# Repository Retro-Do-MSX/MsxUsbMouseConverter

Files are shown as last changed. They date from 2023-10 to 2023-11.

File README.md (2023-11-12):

# MsxUsbMouseConverter
MSX USBマウス変換器  
MSX USB Mouse converter  

## 概要
- PC用USBマウスをMSXのインテリジェントマウスとして使用するための変換器です
- 組み立てにはハンダ付けが必要です
- ケースは購入可能です、3Dプリンター用モデルも無料提供しています
- サポートはありません

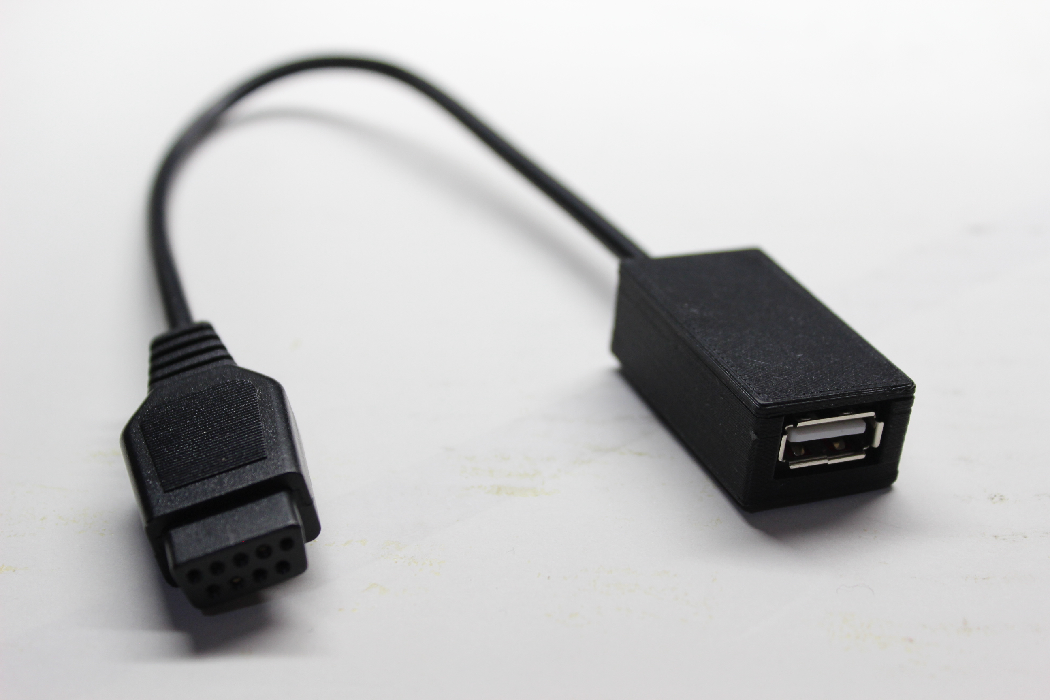
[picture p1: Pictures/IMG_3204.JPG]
converter1


## 動作
- 本機はMSX用マウスモードのみで動作します。モード切替はありません

- ホイール上下で感度(解像度)が5段階変化します

## 動作検証
- 以下のソフトで問題なく動作することを確認しました
  - 秘録 首斬り館 〜逐電屋藤兵衛〜（マウス）
  - スーパーグラフィックツール ダ・ビンチ（マウス）
  - NEOSグラフィックソフト CHEESE2（マウス）
  - FS-A1GT MSX-VIEW（マウス）

- 以下のマウスで動作を確認しています
  - iBuffalo BSMRW21 USB無線マウス
  - Logicool M705 USB無線マウス

- 電力消費の大きなLED付き有線マウスは動作しない可能性があります

## キット内容
- 変換基板 x1
- マイコン基板 (ソフトウェア書込み済) x1
- USB Type A メスコネクタ x1
- 抵抗 22Ω x2
- ピンヘッダ x2
- D-SUB 9ピンコントローラ用ケーブル x1
- ケース (オプション) 上下組 x1
  ※お届けする商品は画像のものと異なる場合があります

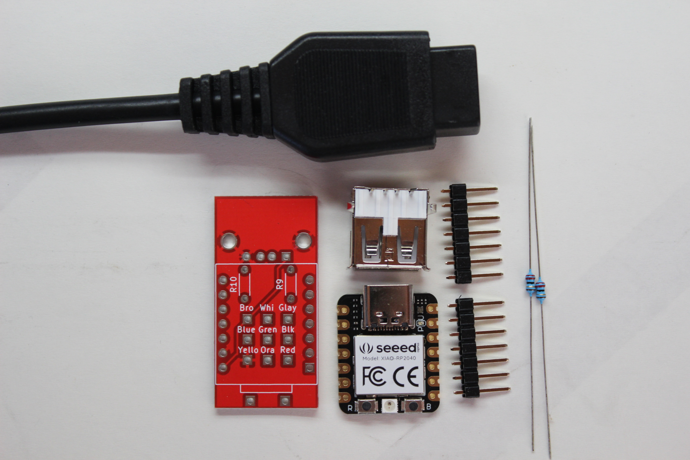
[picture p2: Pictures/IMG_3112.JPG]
parts
  
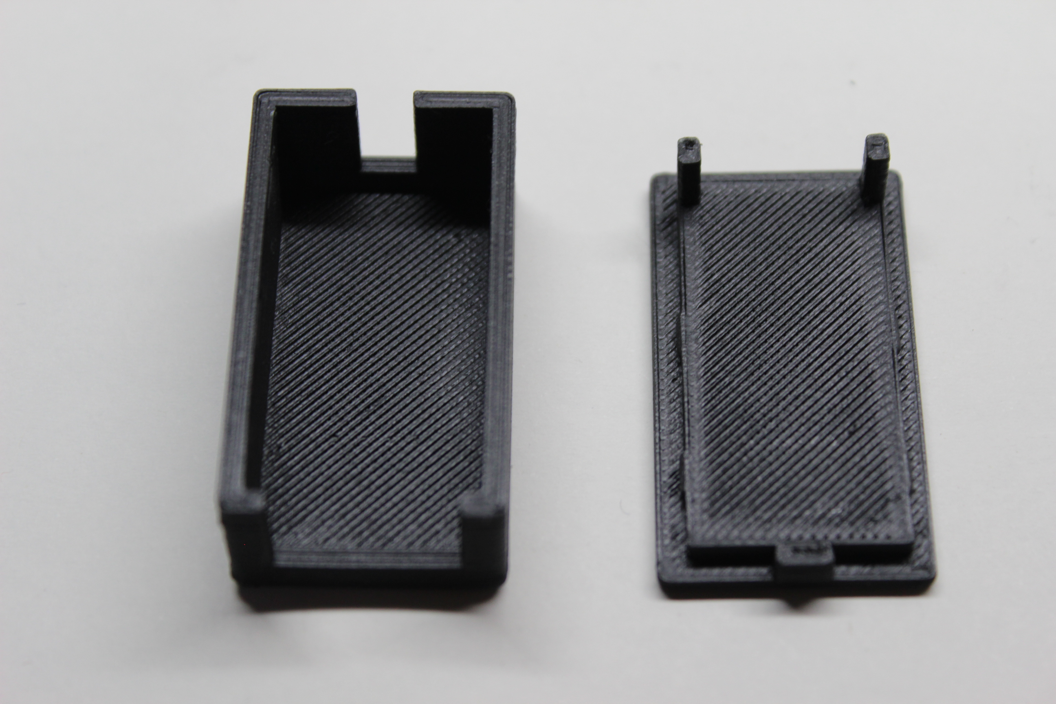
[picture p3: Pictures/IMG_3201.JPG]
case
   

## 注意事項
- マイコン基板のUSB Type Cコネクタは接続しないでください  
  PCと接続すると書き込み済みのファームウェアが消える可能性があります
- 万一プログラムが消えた場合の再書き込みは有償での対応となります

## 組立方法
- D-SUB 9ピンコントローラ用ケーブルの先端を剥き予備ハンダしておきます

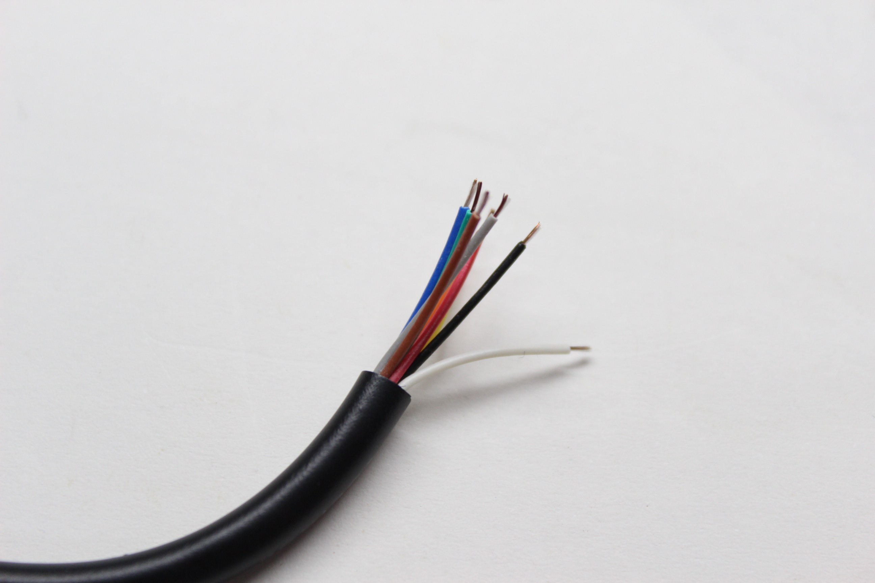
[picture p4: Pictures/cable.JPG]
cable
  

- 変換基板のシルクに書かれた色に合わせて9本のケーブルをハンダ付けします

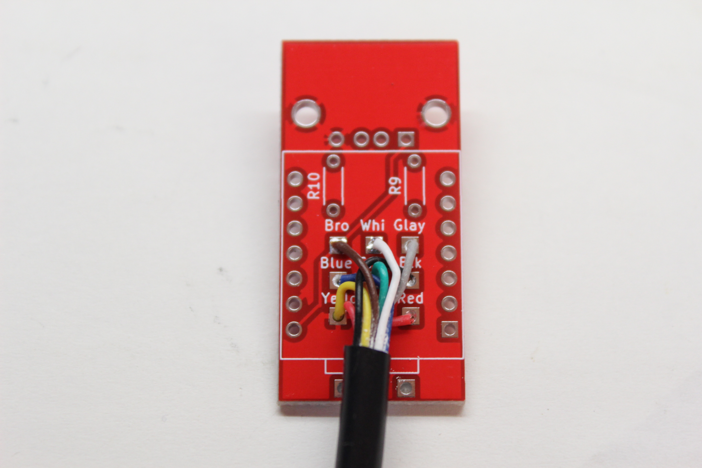
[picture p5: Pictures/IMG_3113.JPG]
1st step


- 部品の足などを使用してケーブルの抜け止めをハンダ付けします（キットには含まれません）
  - シルクの線を目安に黒い被膜がマイコン基板に干渉しないようにします

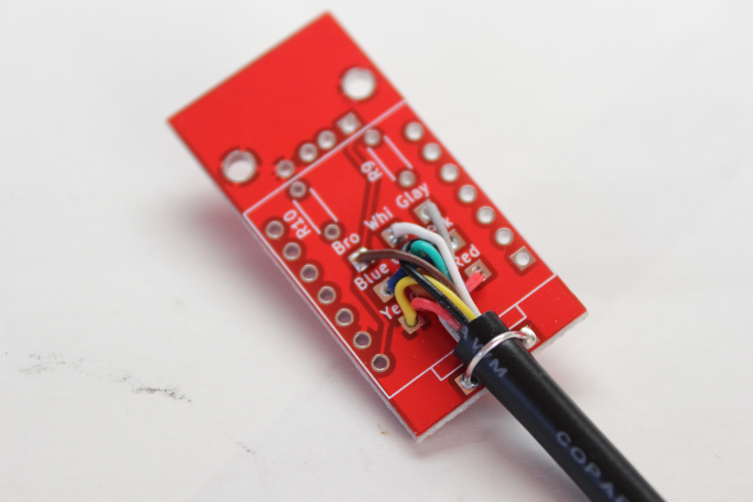
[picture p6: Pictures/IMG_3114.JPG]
2nd step


- 抵抗2本を取り付けます

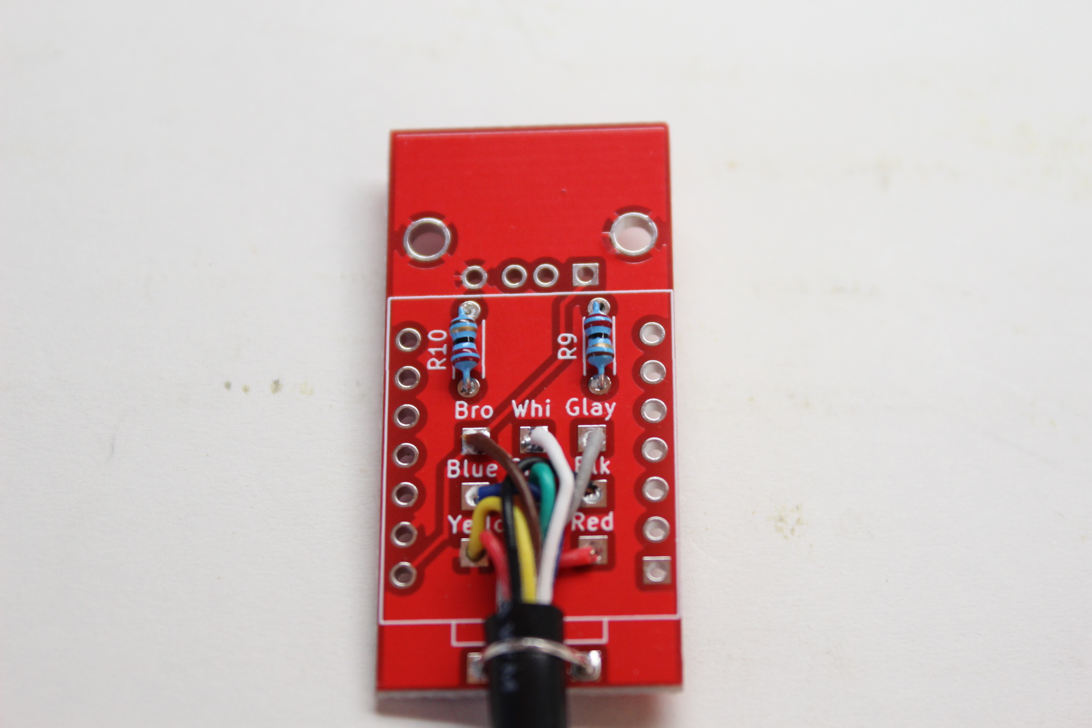
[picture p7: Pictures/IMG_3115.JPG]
3rd step


- USBコネクタとマイコン基板を取り付けます

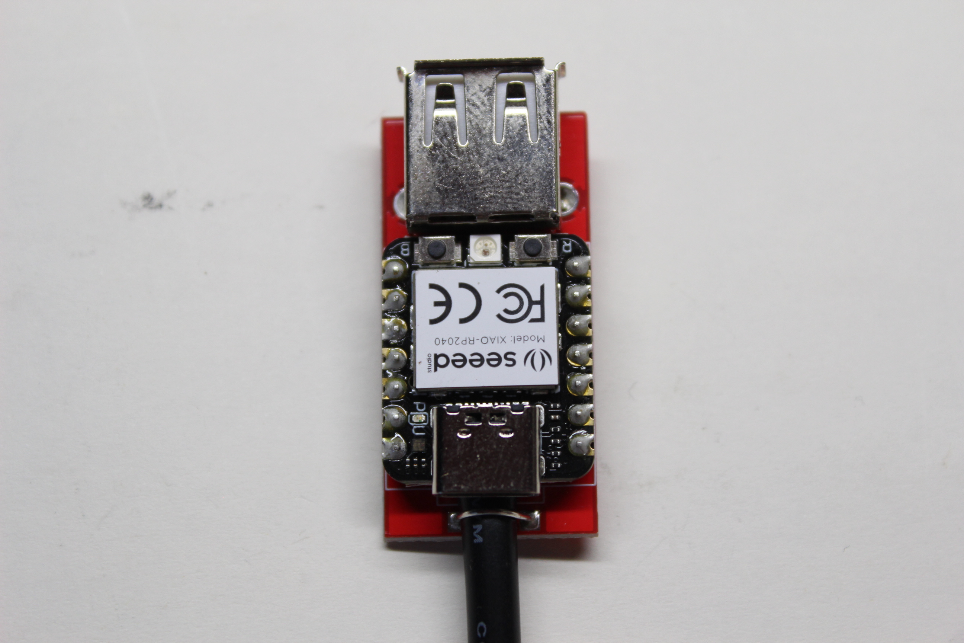
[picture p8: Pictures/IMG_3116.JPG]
4th step


- 裏面に飛び出したピンヘッダやコネクタの足はできるだけ短くカットします
  - ケースに入れない場合は絶縁テープなどを貼りショートしないようにします

- 2023年版は配線漏れがあったため下記のジャンパを追加してください
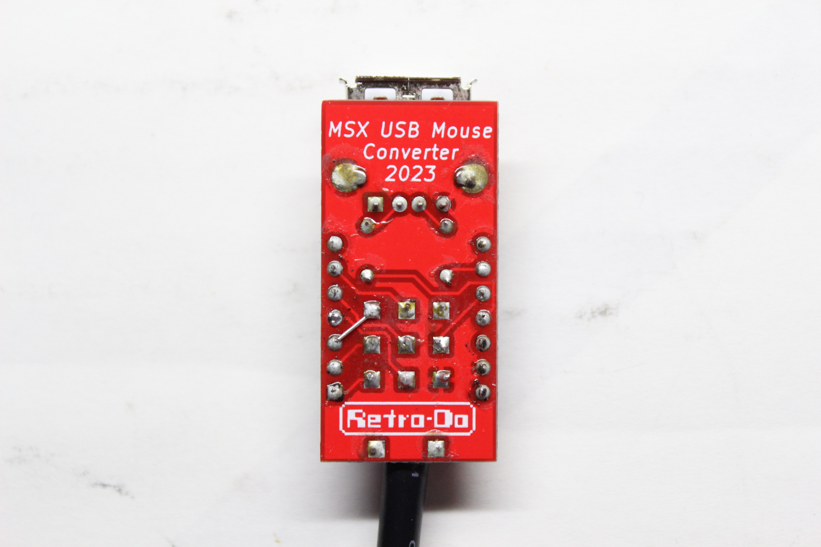
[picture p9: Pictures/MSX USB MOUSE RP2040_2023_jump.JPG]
2023ジャンパ
  

- ケースに入れます

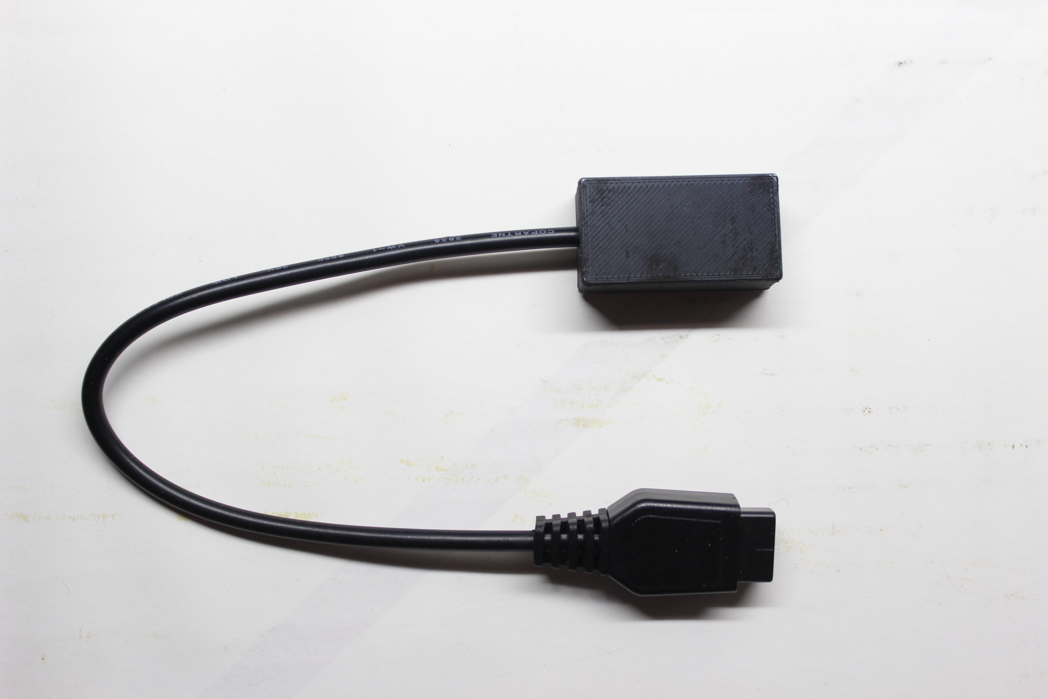
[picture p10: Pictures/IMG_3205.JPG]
converter2


## ケースのプリント用データ

https://github.com/Retro-Do-MSX/MsxUsbMouseConverter/blob/main/Models/Bottom%20MSX%20USB%20Mouse%20Converter%20case.stl
https://github.com/Retro-Do-MSX/MsxUsbMouseConverter/blob/main/Models/Upper%20MSX%20USB%20Mouse%20Converter%20case.stl

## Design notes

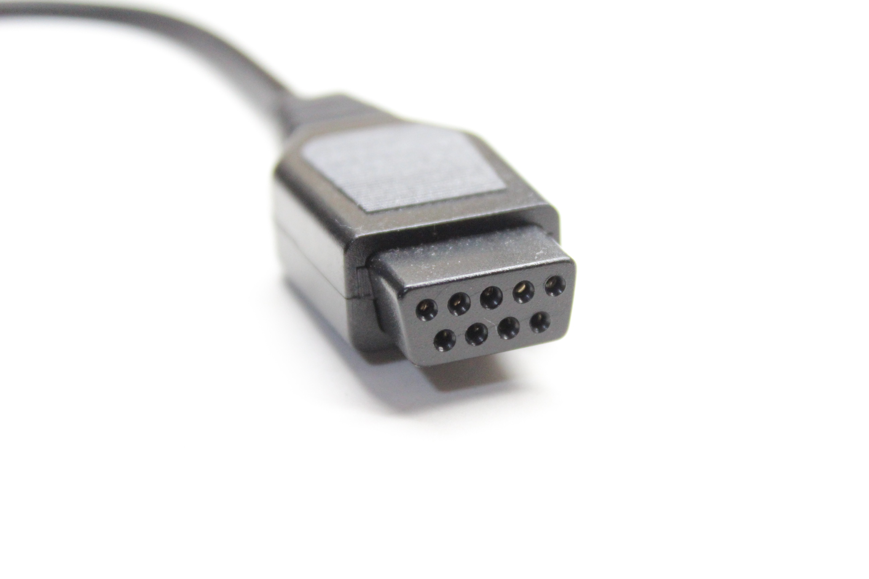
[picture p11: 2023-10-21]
Pictures/JOYcon.JPG

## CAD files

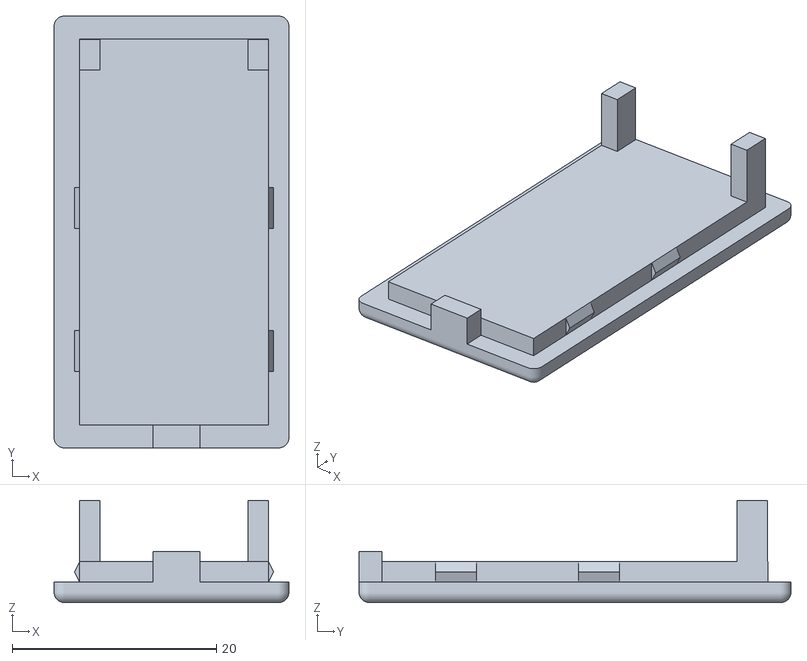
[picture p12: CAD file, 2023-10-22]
Models/Upper MSX USB Mouse Converter case.stl
23.0 x 42.3 x 10.0

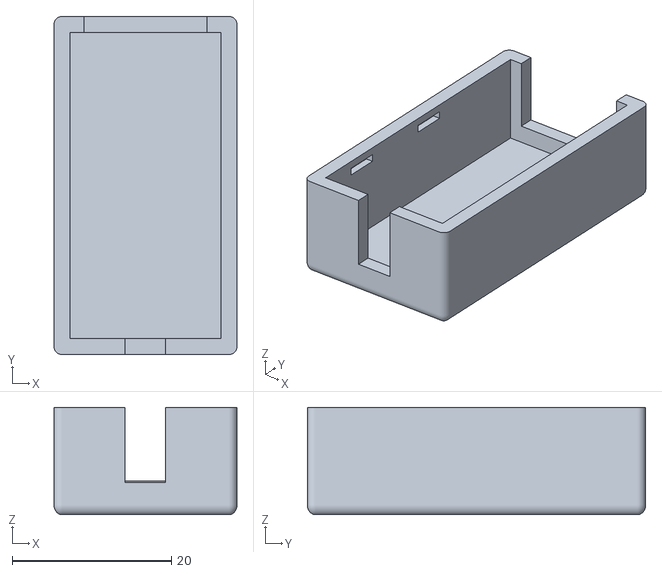
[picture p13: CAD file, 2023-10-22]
Models/Bottom MSX USB Mouse Converter case.stl
23.0 x 42.5 x 13.5

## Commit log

2023-10-21 初期コミット Retro-Do
2023-10-22 ケース写真を追加 Retro-Do
2023-10-22 ケースの3Dモデルを追加 Retro-Do
    [Bottom MSX USB Mouse Converter case.stl, Upper MSX USB Mouse Converter case.stl]
2023-10-22 写真を入れ替え
    Retro-Do
2023-10-22 写真の入れ替え
2023-10-23 USB Type Cコネクタの注意書きを追加
